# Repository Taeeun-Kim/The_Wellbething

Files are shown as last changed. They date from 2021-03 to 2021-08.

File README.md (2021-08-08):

# The Wellbething

Team project of Information visualization module at TU Dresden University.

A smart device that tells you if you've consumed more than the recommended amount of water per day.

### Used tools and techniques

- Arduino ESP32
- C++
- 3D Printer
- Tinkercad
- Final Cut Pro

### Function

- Temperature
- Humidity
- Water Consumption
- Air Quality

### Documentation

[Link to documentation](https://github.com/Taeeun-Kim/The_Wellbething/blob/main/Documents/Gruppe1_Dokumentation.pdf)

### TechnicalDocumentation

[Link to technical documentation](https://github.com/Taeeun-Kim/The_Wellbething/blob/main/Documents/Gruppe1_Technische_Dokumentation.pdf)

### Overview

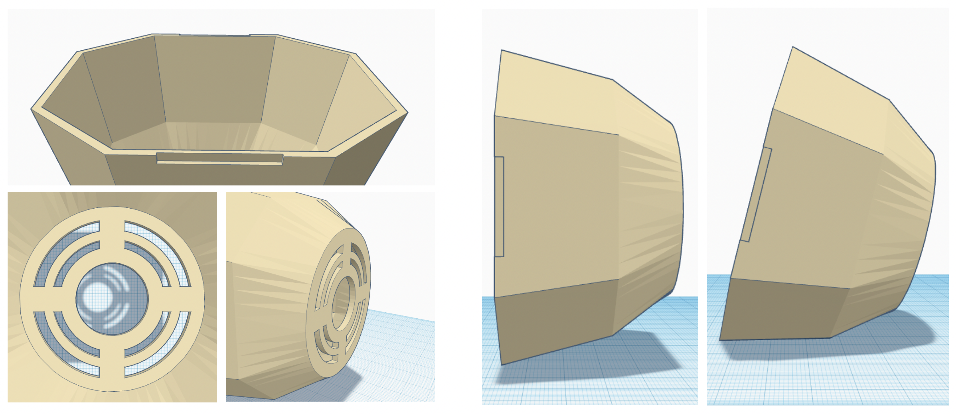
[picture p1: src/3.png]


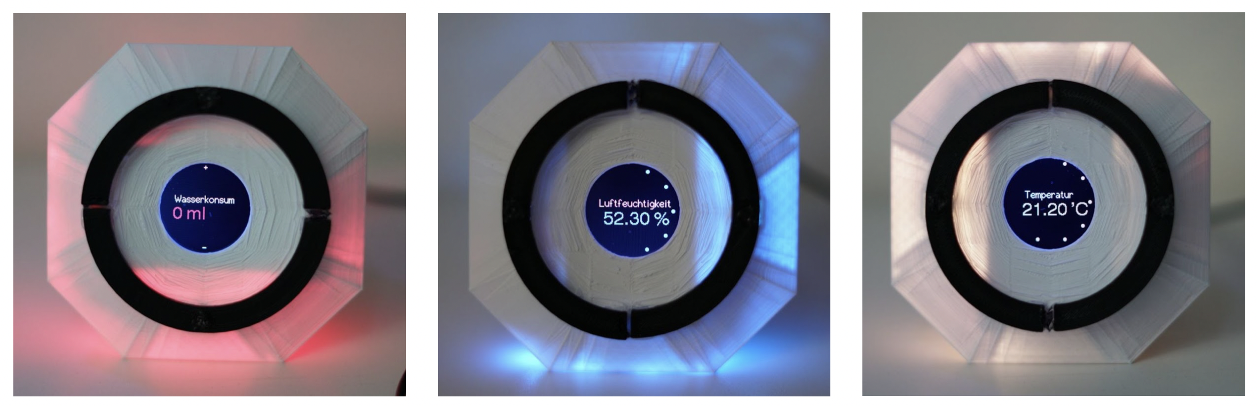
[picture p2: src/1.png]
slack


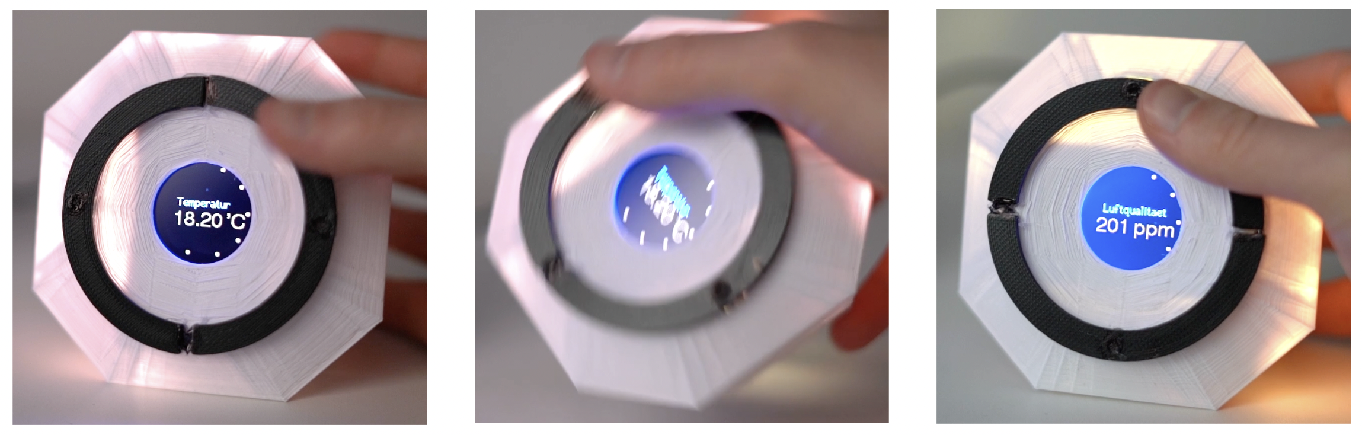
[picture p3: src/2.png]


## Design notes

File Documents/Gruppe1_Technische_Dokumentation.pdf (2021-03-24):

# Technische Dokumentation

### Gruppe 1

### Medieninformatik Projekt Informationsvisualisierung WS 20/21

### Björn Glawe Taeeun Kim Lanea Lilienthal

## Inhaltsverzeichnis

1. Entwicklungsumgebung | 2
1.1 Betriebssystem und Software | 2
1.2 Arduino-Bibliotheken | 2
2. Hardware | 3
2.1 Hardware-Komponenten | 3
2.2 Hardware-Aufbau | 4
3. Software | 5
3.1 Vereinfachtes Klassendiagramm | 5
3.2 Kompilierte Binärdateien und Upload | 6
4. Bedienungsanleitung | 7

## 1. Entwicklungsumgebung

### 1.1 Betriebssystem und Software

- Windows 10
- Visual Studio Code (Version: 1.52.1)
- VSCode Extension: Arduino from Microsoft (Version: 0.3.4)
- Arduino (1.8.13)

### 1.2 Arduino-Bibliotheken

verwendete Arduino-Bibliothek | Version
DHT sensor library | 1.4.0
MQUnifiedsensor | 2.0.1
Adafruit_MPU6050 | 2.0.3
OneWire | 2.3.4
NeoPixelBus | 2.6.0
TFT_eSPI | 2.3.4
SPI | 1.0.0

## 2. Hardware

### 2.1 Hardware-Komponenten

Bauteil | technische Bezeichnung | Funktion
ESP32 | AZDelivery ESP32 Dev Kit C V4 NodeMCU WLAN WiFi Development Board (Link) (https://www.amazon.de/AZDelivery-ESP32-NodeMCU-gratis-eBook/dp/B07Z83MF5W?hvadid=427788576373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) | Mikrocontroller zur Steuerung aller Funktionen
Display | SPI TFT Display 1,8 Zoll mit 128 x 160 Pixeln (mit Kartenslot) (Link) (https://www.amazon.de/AZDelivery-Pixeln-Display-Arduino-Raspberry/dp/B078J5TS2G?hvadid=308872732263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) | visuelle Wiedergabe von Informationen
LED | 8 WS2812B LEDs adressierbare Streifen mit 5050 SMD LEDs | visuelle Wiedergabe von Informationen durch Farbdarstellung
Buttons | Drucktastenschalter | Eingaben durch Drücken des Tasters

DHT-Sensor DHT22 AM2302 Temperatursensor

| und Luftfeuchtigkeitssensor mit Platine (Link) (https://www.az-delivery.de/products/dht22-temperatursensor-modul) | Messung von Temperatur und Luftfeuchtigkeit
MQ-Sensor | MQ-135 Gas Sensor Luftqualität Modul (Link) (https://www.amazon.de/AZDelivery-MQ-135-Sensor-Luftqualit%C3%A4t-Arduino/dp/B07CNNKQ5R?hvadid=380161958296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) | Messung von Luftqualität, misst Anteil an Luftpartikeln
Gyroskop | GY-521 MPU-6050 3-Achsen-Gyroskop und Beschleunigungssensor (Link) (https://www.az-delivery.de/products/gy-521-6-achsen-gyroskop-und-beschleunigungssensor) | Messung von Bewegung, hier Rotation

### 2.2 Hardware-Aufbau

Folgende Grafik zeigt die Verbindungen auf der Platine zu den einzelnen Bauteilen. Dabei dient die Platine als ein kompaktes Mittelstück, an dem alle Bauteile miteinander vereint werden. Das Display wird auf der Rückseite direkt verbunden, alle anderen Sensoren sind auf der Vorderseite direkt oder über Kabel verbunden. Alle notwendigen Verbindungen gehen von der Plantine aus zum ESP32. Durch die Platine werden vor allem 5V, 3v3 und GND nur jeweils einmal mit dem ESP32 verbunden. Dies ermöglicht eine relativ kompakte Bauweise im Tangible.

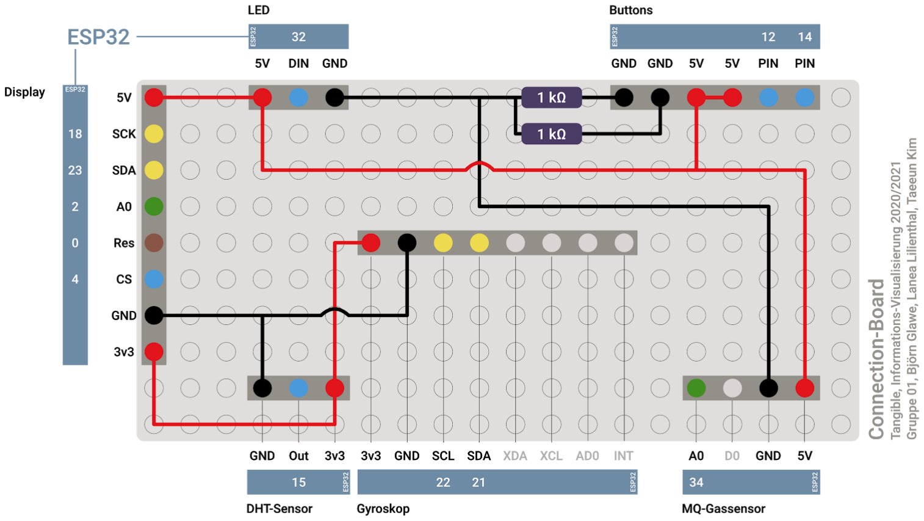
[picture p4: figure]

In der folgenden Abbildung finden sich die Verbindungen von der jeweiligen Komponente zum direkten Pin-Anschlüsse am ESP32. Auf der linken Seite befinden sich jeweils die ESP32-Pins und auf der rechten Seite die Komponenten-Pins. Graue Kreise (Pins) werden nicht angeschlossen.

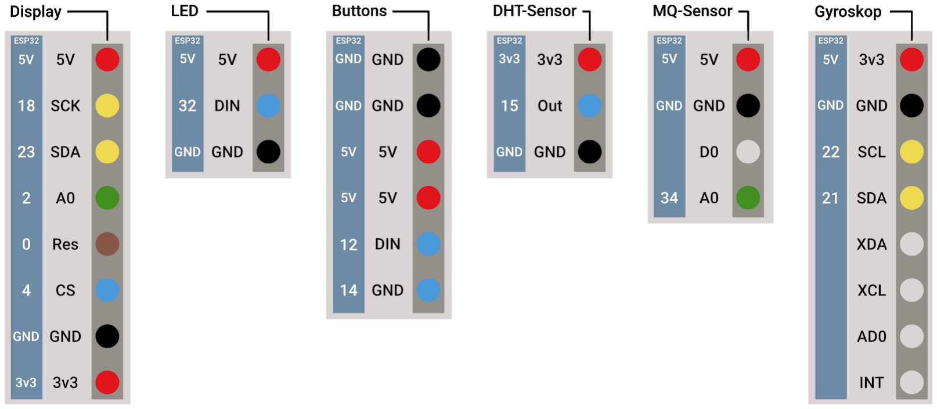
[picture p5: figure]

## 3. Software

### 3.1 Vereinfachtes Klassendiagramm

Zentral ist die main.ino-Datei. Alle Funktionen werden hier initialisiert, aufgerufen und verknüpft. Zu jedem Modul, bzw. für den Wasserkonsum zusätzlich, existiert eine eigene Klasse, in der für das Projekt notwendige Funktionen implementiert wurden. Diese können jeweils von der main.ino aufgerufen und verwendet werden.

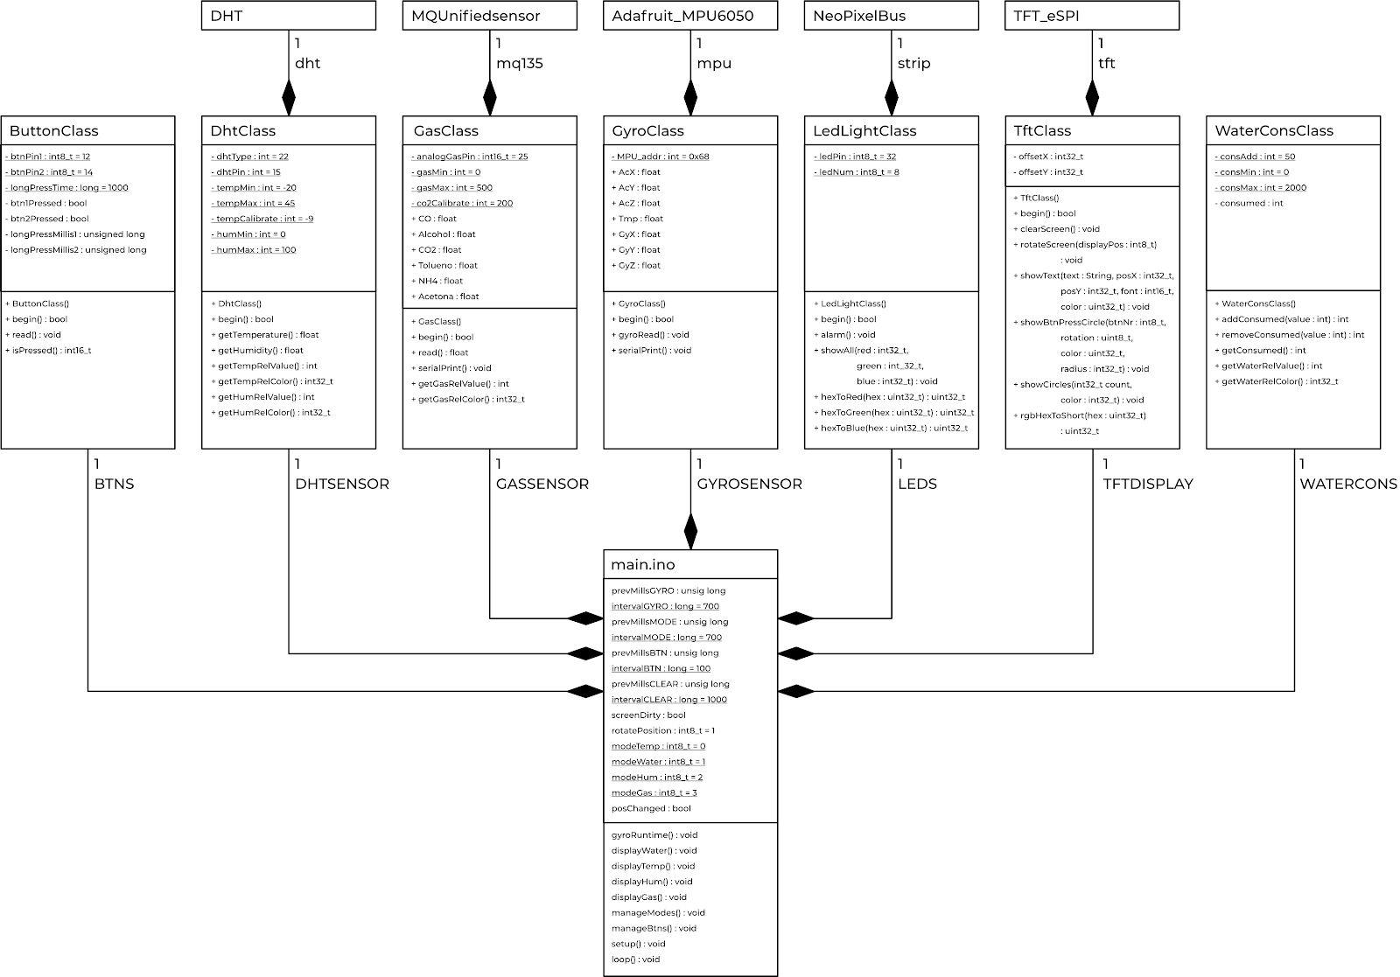
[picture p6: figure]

### 3.2 Kompilierte Binärdateien und Upload

Unter ./build sind alle kompilierten Dateien und Sourcecode nach dem letzten build-Vorgang zu finden, inklusive Bibliotheken.
In der Konfigurationsdatei .vscode/arduino.json werden durch die Angabe von “output”: “build” alle Dateien die im Projekt zur Kompilierung, sowie auch die kompilierten Binärdateien, im Ordner ./build abgelegt.
Für den Upload auf den ESP32 werden folgende Dateien benötigt:
- build\button.cpp.bin
- build\button.cpp.partitions.bin
Die Bezeichnung button innerhalb des Dateinamen spielt dabei keine Rolle.

Für den Upload der Binärdateien lautet der Konsolenbefehl wie folgt:

Um den Konsolenbefehl auf dem eigenen System zu finden, geht man wie folgt vor. In der Arduino IDE unter File>Preferences die Option “Show verbose output during” > “upload” den Haken setzen (true).
Daraufhin einen Upload mit Arduino IDE auf einen ESP32 starten und in der letzten Zeile vom Arduino Output, bevor der Upload startet, ist der Uploadbefehl mit allen Pfadangaben in der eigenen eingerichteten Entwicklungsumgebung zu finden. Diesen Befehl kopieren und entsprechende Pfade (in dem Beispiel grün markiert) durch die kompilierten Binärdatei-Pfade ersetzen.

farbliche Codierung:
ESP-Uploader-Files (kommen mit der ESP32-Board-Packages) Controller-Configurations (spezifische Einstellungen für den Upload)
kompilierte Projektdateien (zuvor beschriebene Dateien unter ./build)

schematischer Upload-Konsolen-Befehl ([...] kennzeichnet den Systempfad zur Datei):

[...]/esptool.exe --chip esp32 --port COM3 --baud 921600 --before default_reset --after hard_reset write_flash -z --flash_mode dio --flash_freq 80m --flash_size detect 0xe000 [...]/boot_app0.bin 0x1000 [...]/bootloader_qio_80m.bin 0x10000 [...]\button.cpp.bin 0x8000 [...]\button.cpp.partitions.bin

Beispiel von der eigenen Entwicklungsumgebung:

C:\Users\rumpe\AppData\Local\Arduino15\packages\esp32\tools\esptool_py\2.6.1/esptool.exe --chip esp32 --port COM3 --baud 921600 --before default_reset --after hard_reset write_flash -z --flash_mode dio --flash_freq 80m --flash_size detect 0xe000 C:\Users\rumpe\AppData\Local\Arduino15\packages\esp32\hardware\esp32\1.0.4/tools/partition s/boot_app0.bin 0x1000
C:\Users\rumpe\AppData\Local\Arduino15\packages\esp32\hardware\esp32\1.0.4/tools/sdk/bin/b ootloader_qio_80m.bin 0x10000 C:\Users\rumpe\CloudStation\Drive\UNI_5\InfoVis\infovis-2021-gruppe-1\build\button.cpp.bin 0x8000
C:\Users\rumpe\CloudStation\Drive\UNI_5\InfoVis\infovis-2021-gruppe-1\build\button.cpp.par titions.bin

## 4. Bedienungsanleitung

Das Tangible hat vier grundlegende Funktionen, die für den Nutzer relevant sind:
- zwischen den verschiedenen Ausgabewerten wechseln
- den aktuellen Wert nachschauen
- Getrunkenes eintragen
- Warnfunktion zum Trinken.

Es gibt vier unterschiedliche Ansichten (Wasserkonsum, Temperatur, Luftfeuchtigkeit und Luftqualität) zwischen denen der Nutzer wechseln kann. Das Wechseln funktioniert, indem das Tangible um 90° gedreht wird. Das Tangible ist hierbei so designt, dass es auf allen dieser vier Seiten stehen kann.
Sobald das Tangible gedreht wird, wechselt die Ansicht. Wenn das Tangible also z.B. auf Temperatur eingestellt ist und es gedreht wird, wechselt es zur nächsten Ansicht (z.B. Luftfeuchtigkeit).
Jede dieser Ansichten zeigt den jeweiligen aktuellen Wert im Raum in dem das Tangible sich befindet. Also die aktuelle Temperatur in °C, Luftfeuchtigkeit in %, Luftqualität in ppm und die Menge des bisher Getrunkenen des Tages in ml. Zusätzlich zur textuellen Anzeige des Wertes befindet sich am Rand des Displays eine visuelle Anzeige in Form von Kreisen, deren Anzahl und Farbe je nach Wert variiert. Ein höherer Temperaturwert bedeutet also auch mehr Punkte.
Die Farbe der Punkte orientiert sich auch am aktuellen Wert und bezieht sich auf die Farbskala der jeweiligen Ansicht (z.B. Dunkelrot für sehr hohe Temperaturen). Zusätzlich dazu leuchtet das Tangible in der entsprechenden Farbe.
Bei der Wasserkonsum-Ansicht gibt es des Weiteren die Funktion des Eintragens. Dazu befinden sich zwei Knöpfe ober- und unterhalb des Displays. Der obere Knopf ist hierbei dazu da die Milliliterzahl des Getrunkenen anzupassen. Sobald der Knopf gedrückt wird, erhöht sich die Anzahl in 50 ml Schritten und das Display und die Farbe des Tangibles passen sich entsprechend an. Mit der unteren Taste kann die Zahl jeweils um 50 ml verringert werden (z.B. bei Fehleingaben).
Letztlich gibt es noch eine Warnfunktion, die aber bisher noch nicht umgesetzt ist. Diese soll den Nutzer in bestimmten Zeitabschnitten warnen, wenn über einen längeren Zeitraum nichts oder nicht genug getrunken wurde. Diese Warnung erfolgt über ein Aufleuchten und eine Vibration des Tangibles, die ein paar Sekunden anhält.

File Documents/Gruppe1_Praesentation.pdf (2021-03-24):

# Konzeption und Design eines Tangibles zur Unterstützung des gesunden Wasserbedarfs

Professur Mediengestaltung

Fakultät Informatik / TU Dresden

KP Medieninformatik – Informationsvisualisierung

Björn Glawe
Taeeun Kim
Lanea Lilienthal

## Fr, 12. MRZ (virtuell)

# The Wellbething

# Gliederung

# ende

# Idee

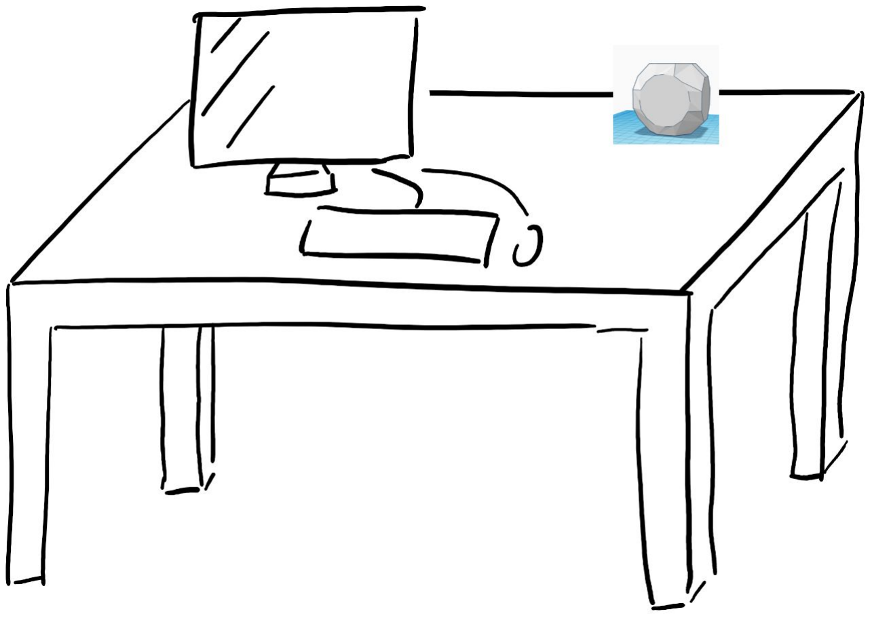
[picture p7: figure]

# - häufig zu geringe Flüssigkeitsaufnahme - Flüssigkeitsbedarf variiert durch Umgebung - Wohlbefinden und Leistungsfähigkeit erhöhen - stets präsentes Tangible mit Erinnerungen - jederzeit erreichbar als mobile App

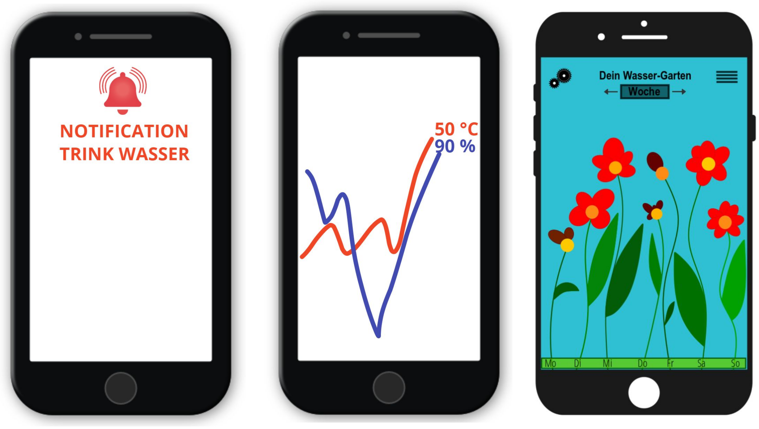
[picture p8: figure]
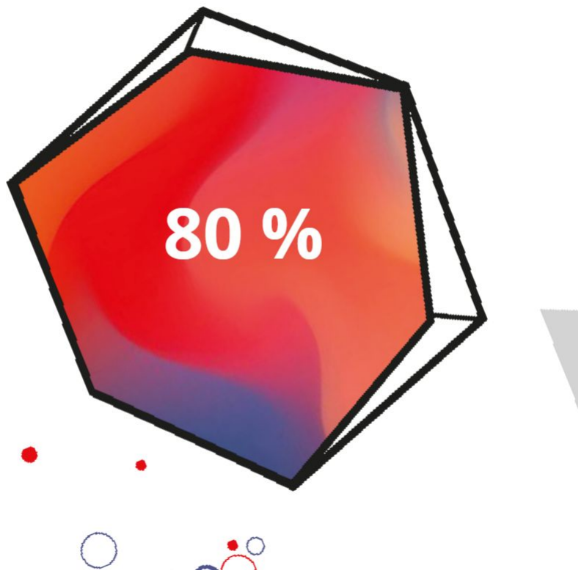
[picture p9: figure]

KP Medieninformatik - Informationsvisualisierung | WS 20/21 | Björn Glawe, Taeeun Kim, Lanea Lilienthal | 3

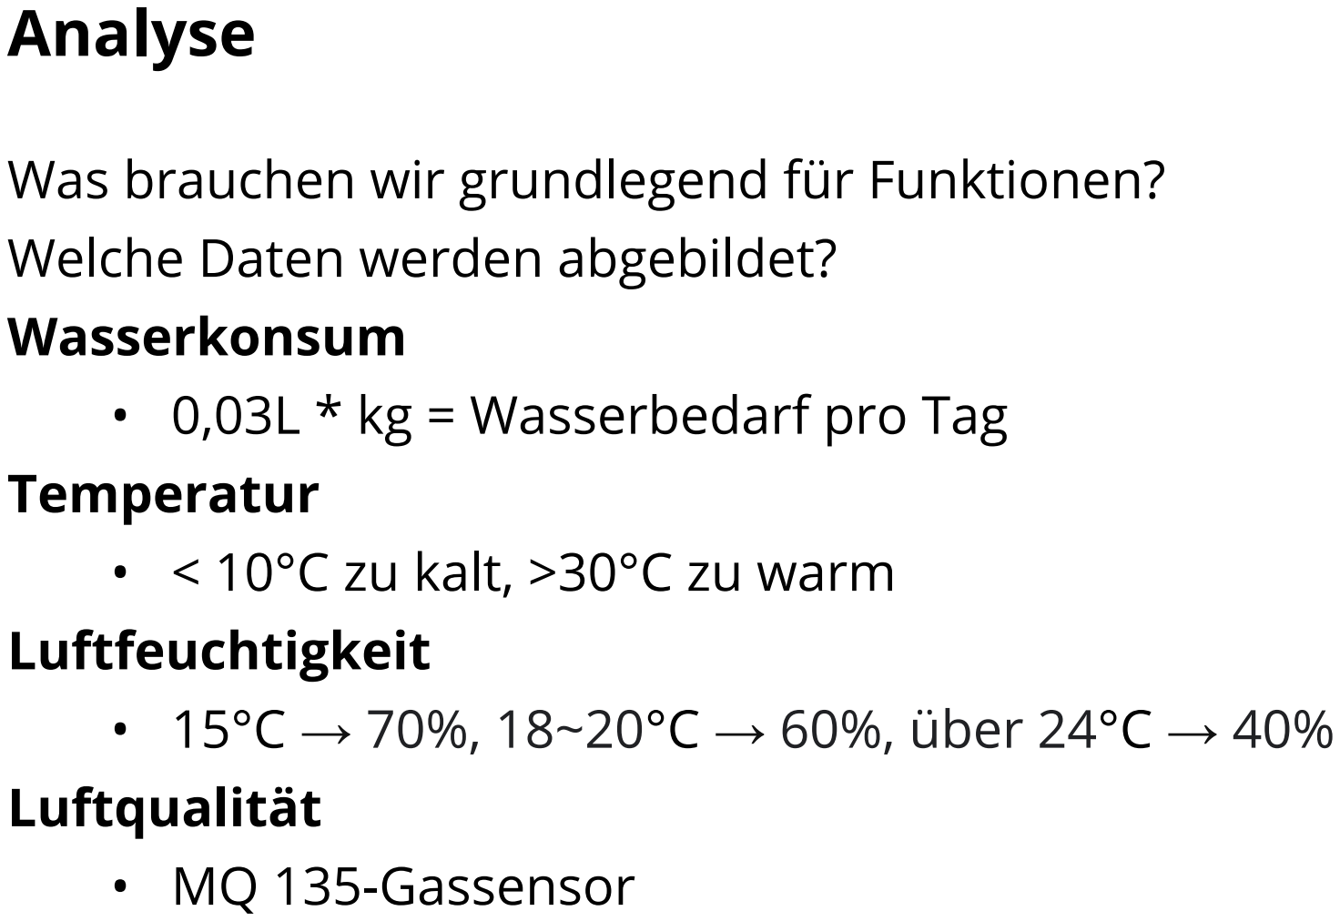
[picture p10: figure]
Analyse; Welche Daten werden abgebildet?; Wasserkonsum • 0,03L * kg = Wasserbedarf pro Tag; Temperatur • < 10°C zu kalt, >30°C zu warm Luftfeuchtigkeit; Luftqualität; • MQ 135-Gassensor

# Was brauchen wir grundlegend für Funktionen?

# - 15°C → 70%, 18~20°C → 60%, über 24°C → 40%

KP Medieninformatik - Informationsvisualisierung | WS 20/21 | Björn Glawe, Taeeun Kim, Lanea Lilienthal | 4

# Design Körper - 3D CAD Modelle

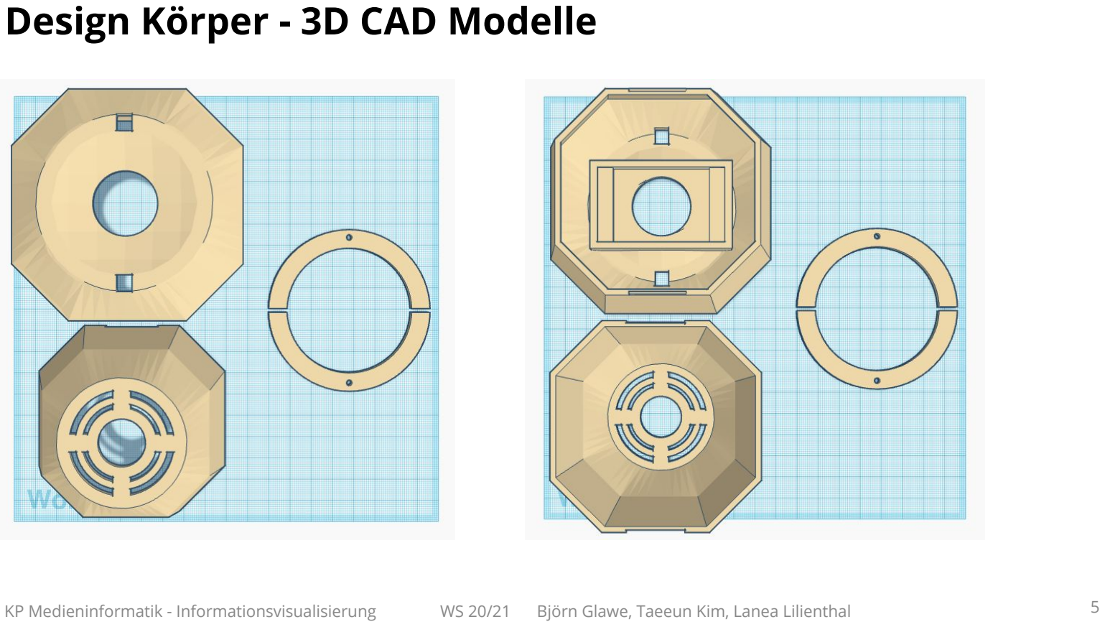
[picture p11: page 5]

KP Medieninformatik - Informationsvisualisierung | WS 20/21 | Björn Glawe, Taeeun Kim, Lanea Lilienthal | 5

# Design Körper - Vorderseite

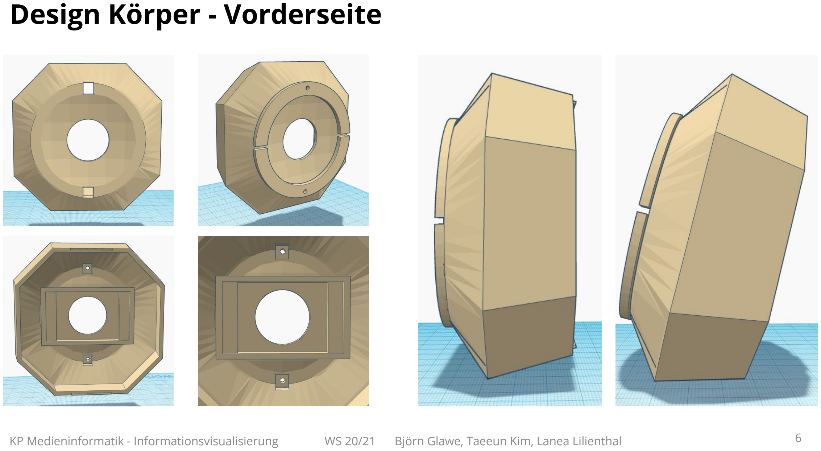
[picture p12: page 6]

KP Medieninformatik - Informationsvisualisierung | WS 20/21 | Björn Glawe, Taeeun Kim, Lanea Lilienthal | 6

# Design Körper - Rückseite

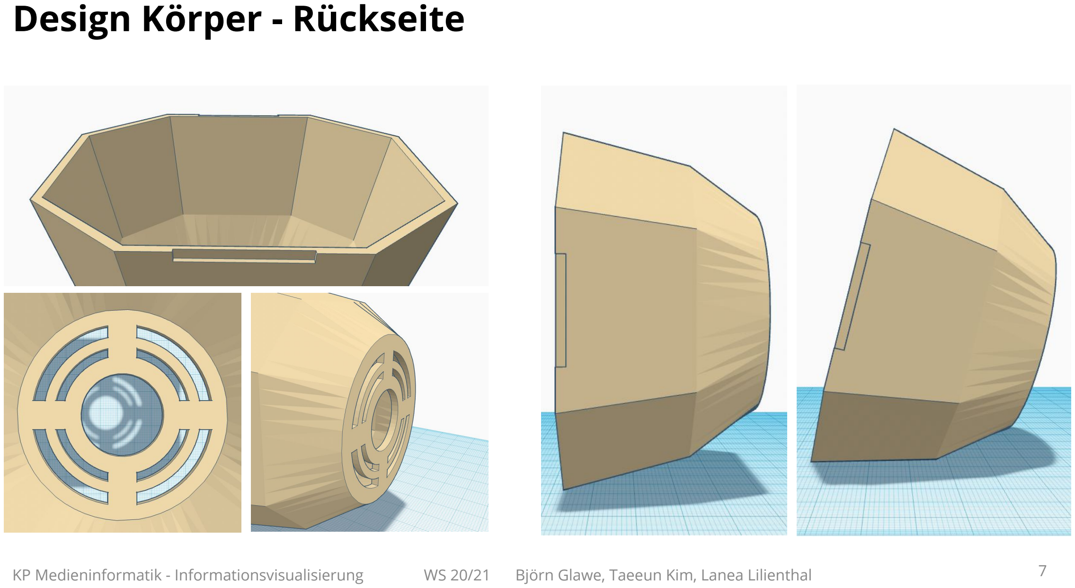
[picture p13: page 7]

KP Medieninformatik - Informationsvisualisierung | WS 20/21 | Björn Glawe, Taeeun Kim, Lanea Lilienthal | 7

# Design Körper - High Fidelity Prototyp

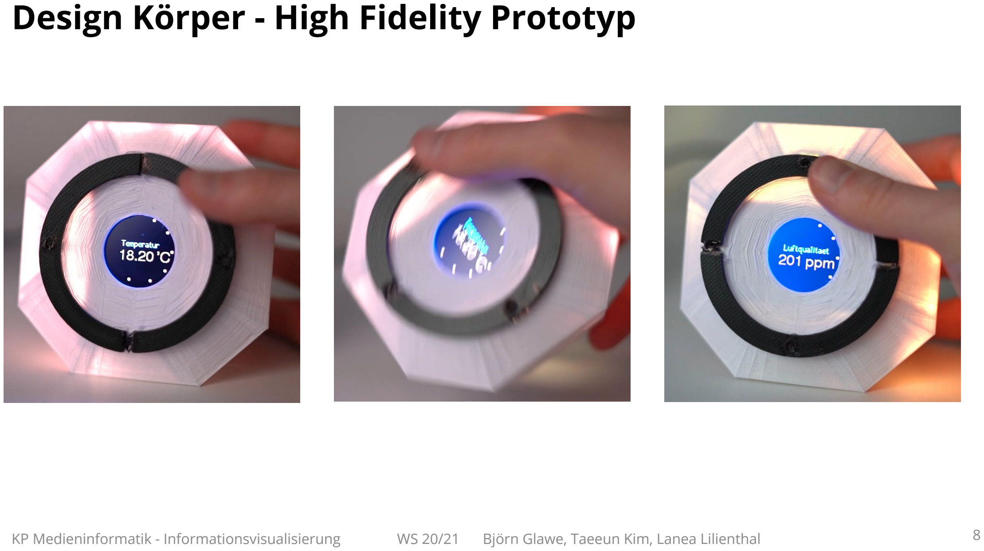
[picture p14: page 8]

KP Medieninformatik - Informationsvisualisierung | WS 20/21 | Björn Glawe, Taeeun Kim, Lanea Lilienthal | 8

# Screendesign - Tangible

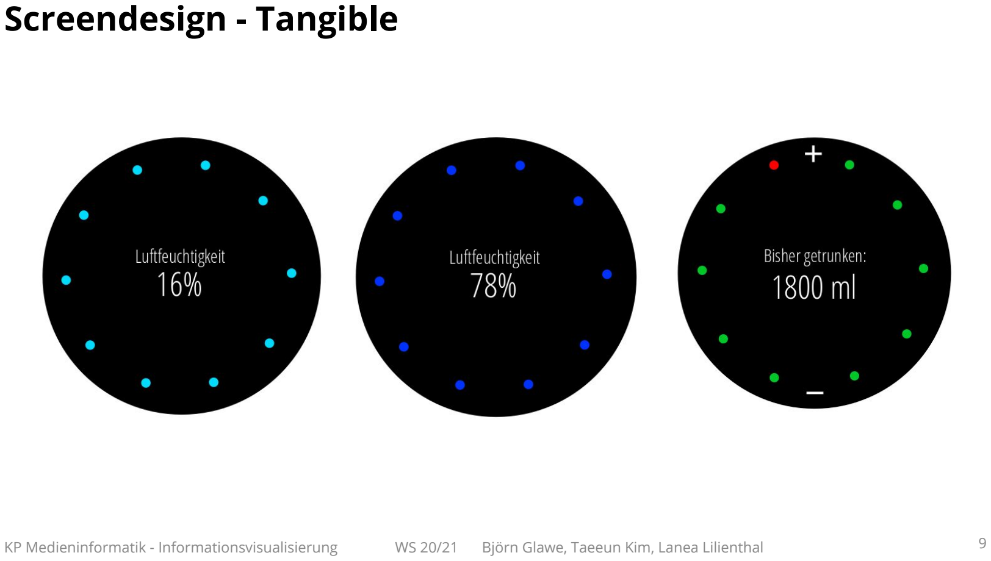
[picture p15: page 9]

KP Medieninformatik - Informationsvisualisierung | WS 20/21 | Björn Glawe, Taeeun Kim, Lanea Lilienthal | 9

# Screendesign - Tangible

# Alternative Designs

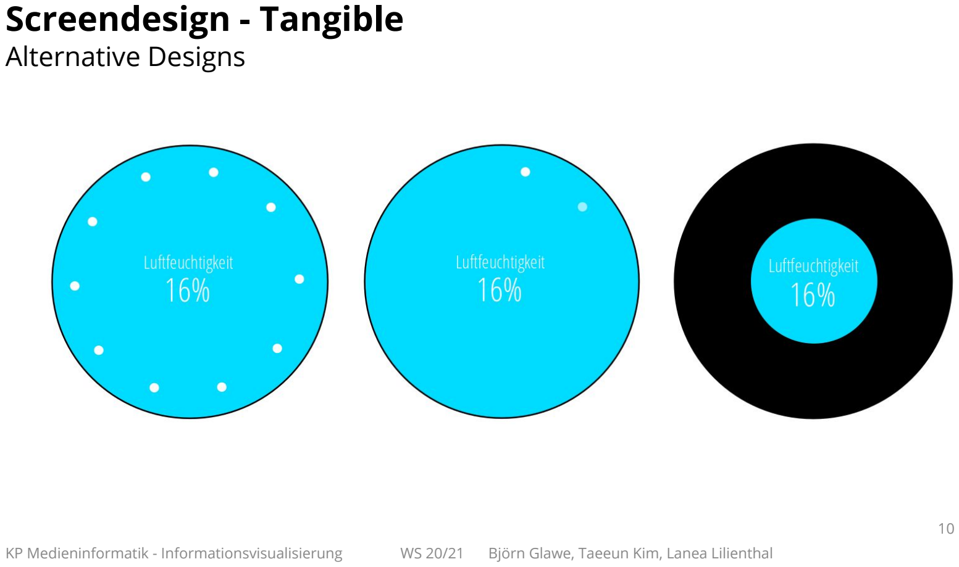
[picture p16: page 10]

KP Medieninformatik - Informationsvisualisierung | WS 20/21 | Björn Glawe, Taeeun Kim, Lanea Lilienthal

# Screendesign - Tangible

# Finale Umsetzung

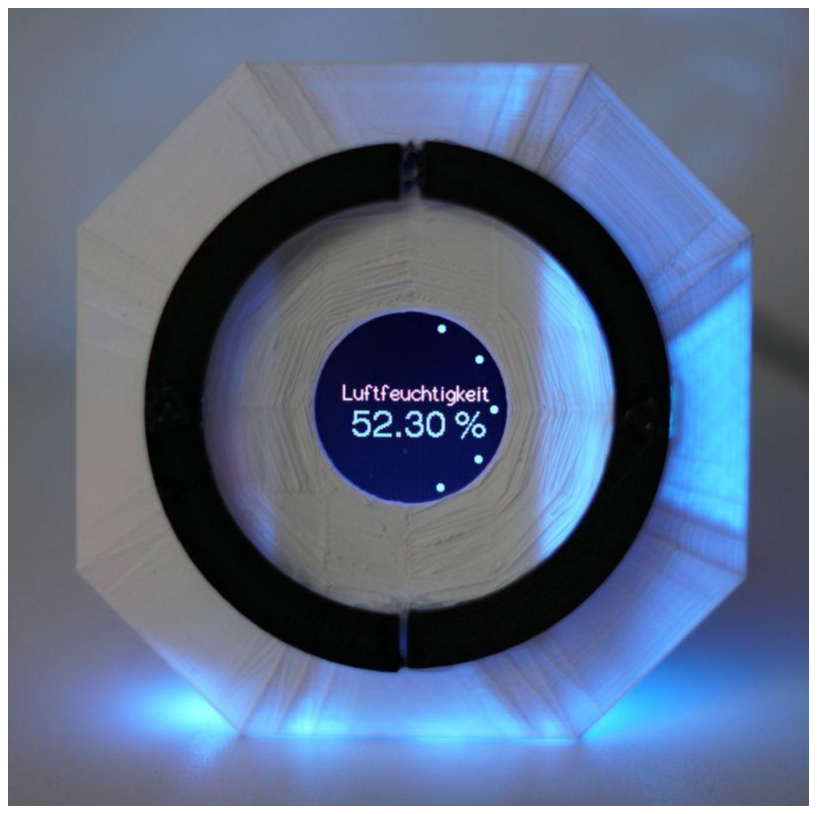
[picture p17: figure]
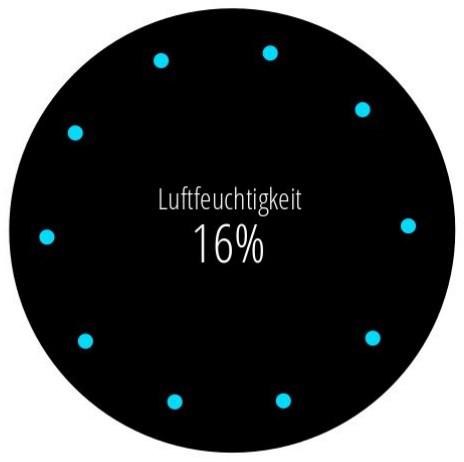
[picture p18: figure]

# Screendesign - Tangible

# Finale Umsetzung

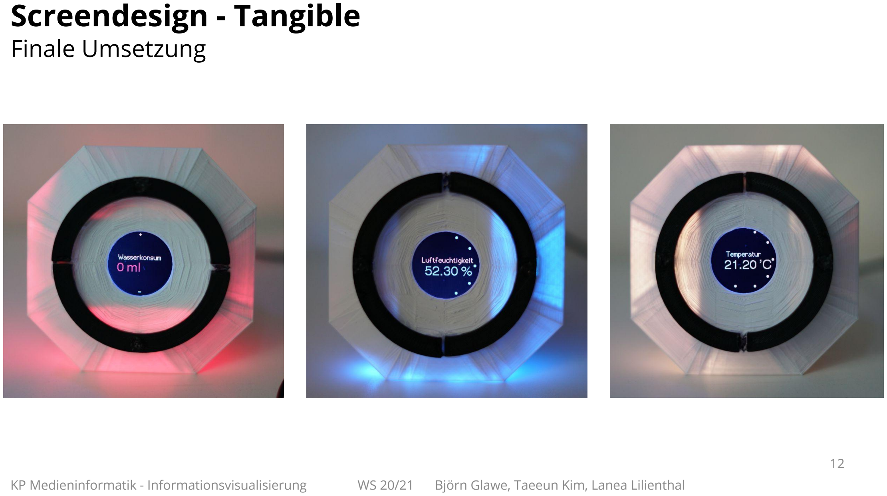
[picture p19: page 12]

# Funktionen - Tangible

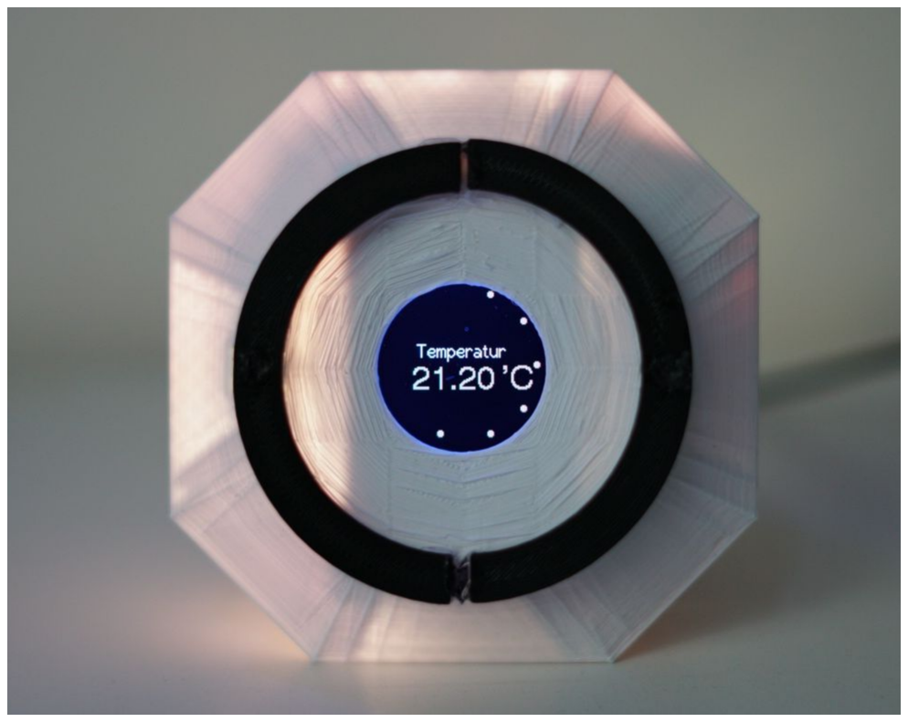
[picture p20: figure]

# Anzeige - aktuelle Zahlenwerte & farbliches Leuchten

# Drehen - Ansichtswechsel

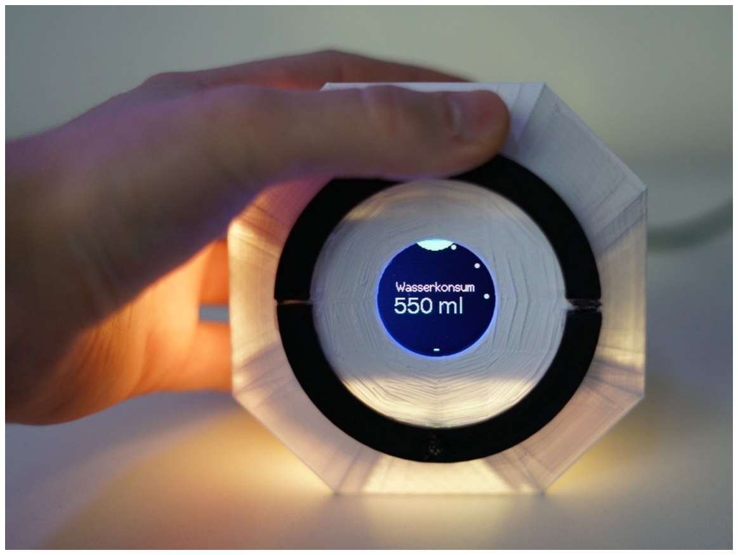
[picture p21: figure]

# Eingabe - Wasserkonsum hinzufügen / entfernen

# Erinnerung

# - Blinken & Vibrieren bei geringe Flüssigkeit oder schlechte Luftqualität

KP Medieninformatik - Informationsvisualisierung | WS 20/21 | Björn Glawe, Taeeun Kim, Lanea Lilienthal | 13

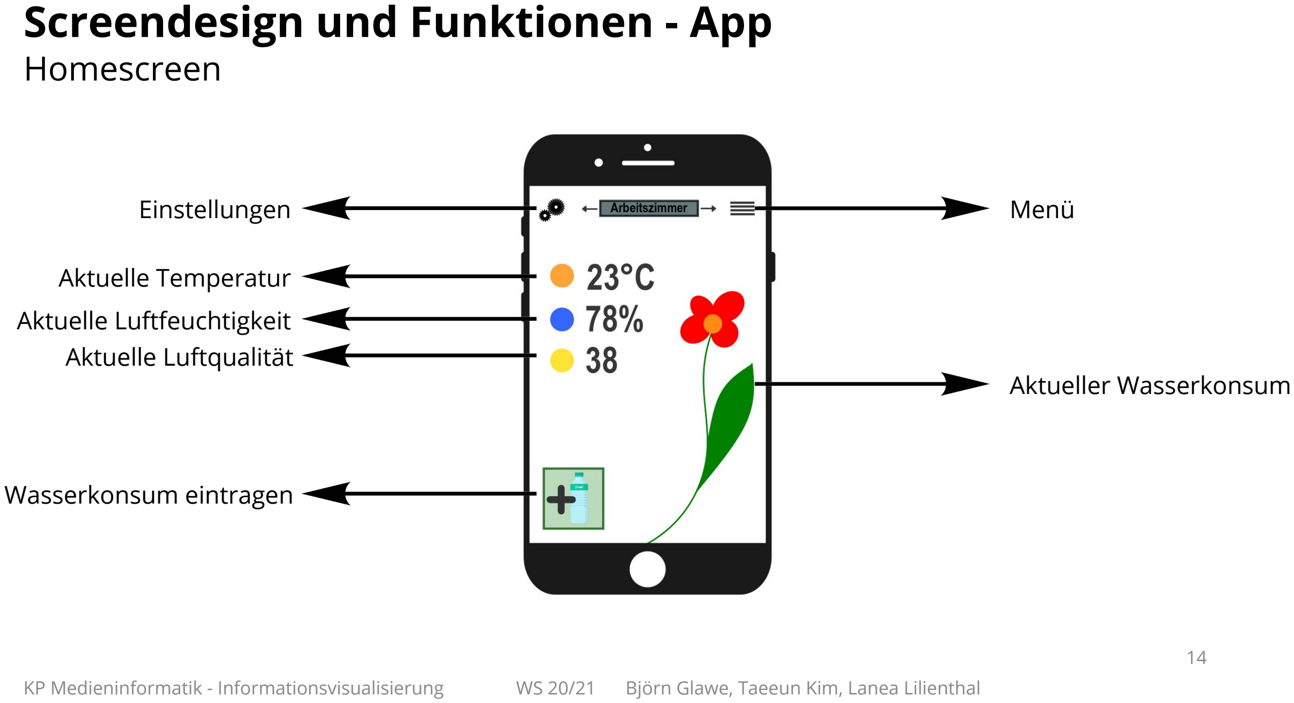
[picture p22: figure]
Screendesign und Funktionen - App; Einstellungen; Aktuelle Temperatur; Aktuelle Luftfeuchtigkeit; Aktueller Wasserkonsum; Menü; Aktuelle Luftqualität; Wasserkonsum eintragen; Homescreen

# Screendesign und Funktionen - App

# Verläufe

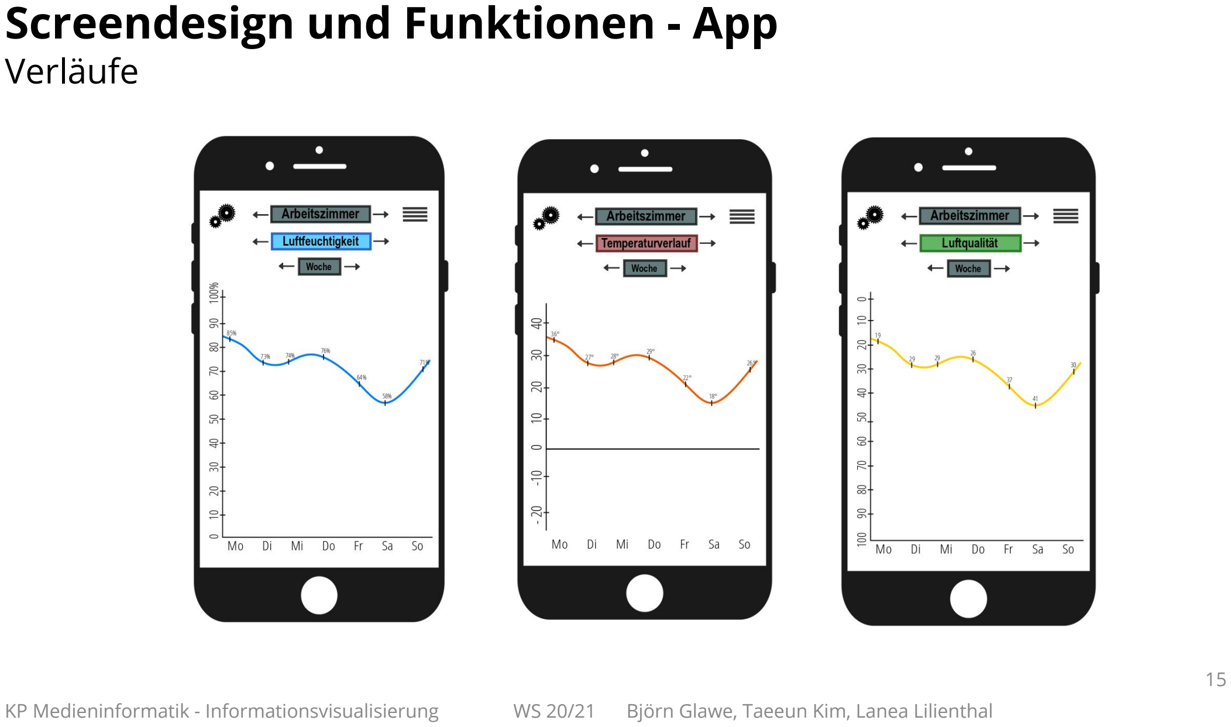
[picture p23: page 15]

# Screendesign und Funktionen - App

# Juxtaposed View

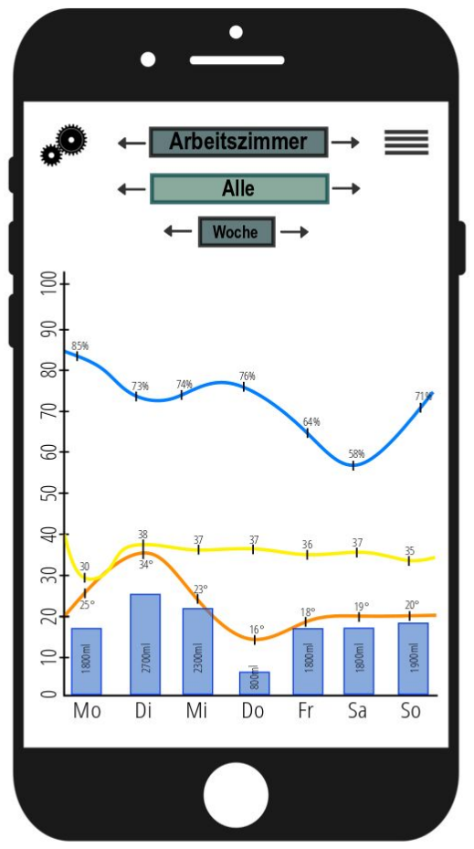
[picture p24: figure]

# Screendesign und Funktionen - App

# Wassergarten - Wochenansicht

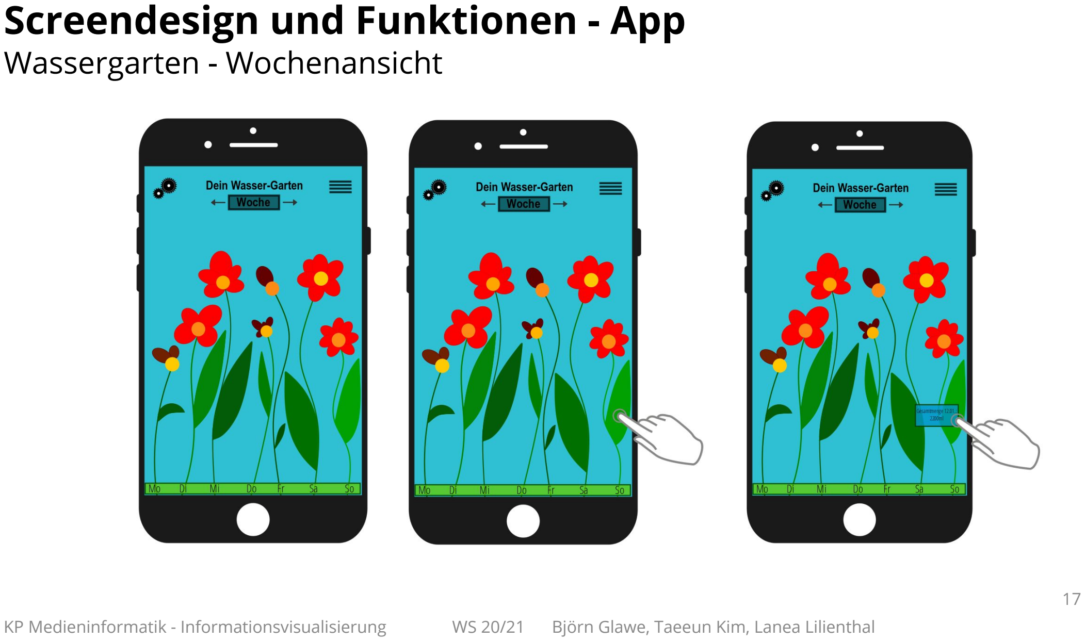
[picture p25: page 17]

# Screendesign und Funktionen - App

# Wassergarten - Tagesansicht

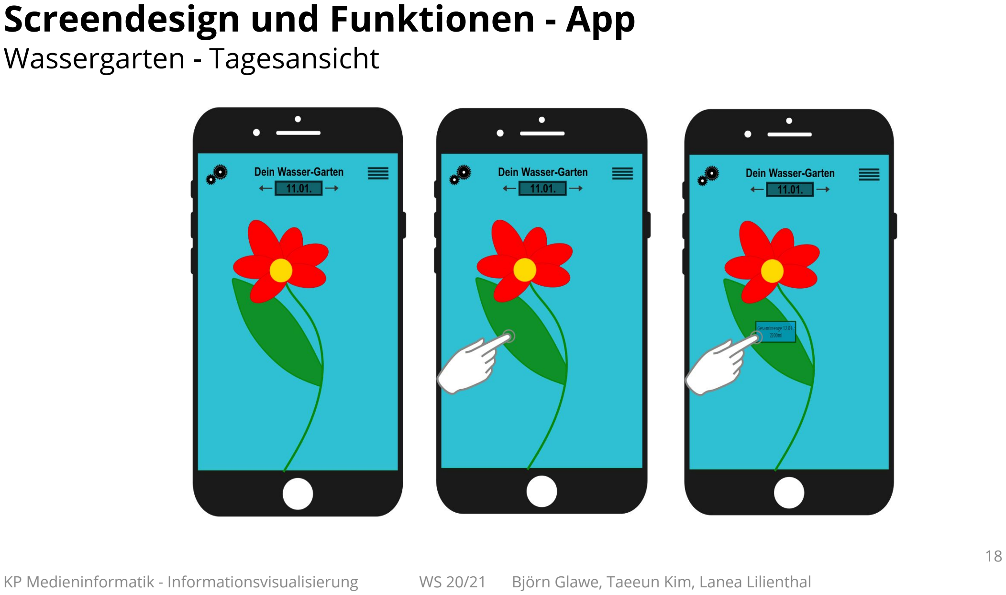
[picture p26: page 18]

# Screendesign und Funktionen - App

# Wasserkonsum eintragen

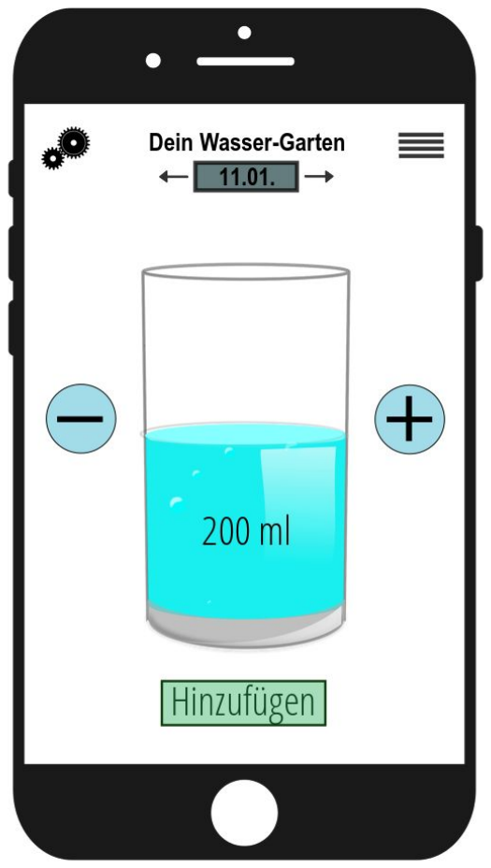
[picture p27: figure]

# Quellen

1. Gesundheitsportal Österreich -; 3. The Engineering ToolBox -

# https://www.gesundheit.gv.at/leben/ernaehrung/info/fluessigkeitsbedarf 2. Chemie.de - https://www.chemie.de/lexikon/Luftfeuchtigkeit.html

# https://www.engineeringtoolbox.com/air-contaminants-limits-d_1538.html 4. Deutsche Gesellschaft für Ernährung - https://www.dge.de/ 5. Instructables - https://www.instructables.com/Air-Qualiy-Monitoring/

KP Medieninformatik - Informationsvisualisierung | WS 20/21 | Lanea Lilienthal | 20

# Vielen Dank!


KP Medieninformatik - Informationsvisualisierung | WS 20/21 | Lanea Lilienthal | 21

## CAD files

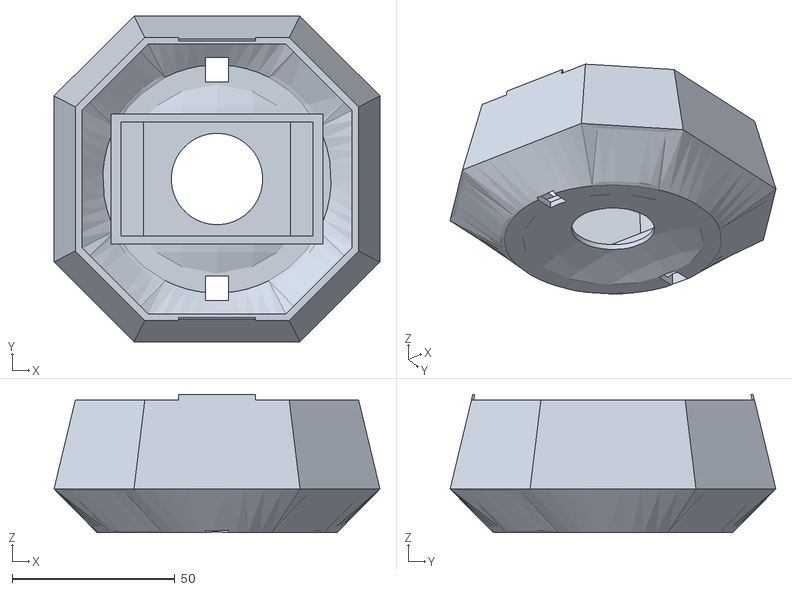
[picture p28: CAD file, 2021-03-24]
Körperkonstruktion/final-version/Tangible-front.stl
100.1 x 100.0 x 42.5

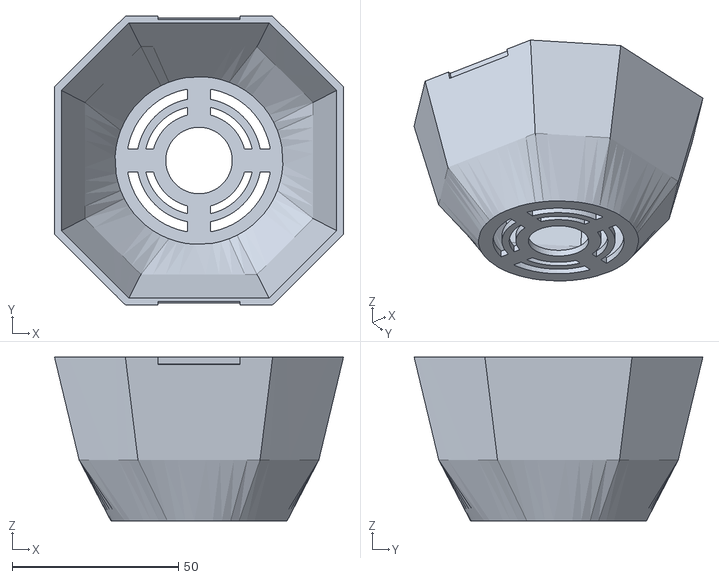
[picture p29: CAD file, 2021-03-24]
Körperkonstruktion/final-version/Tangible-back.stl
87.0 x 86.9 x 49.2

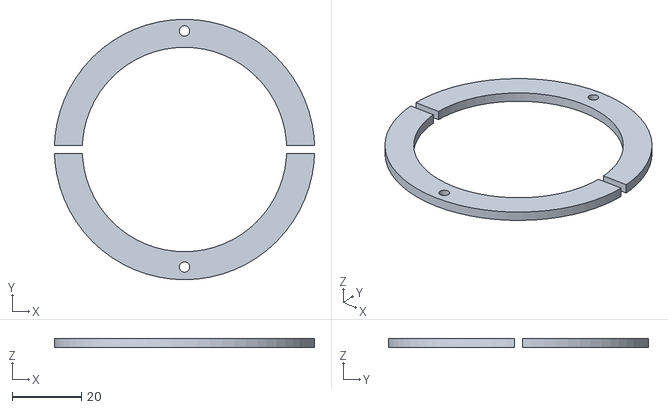
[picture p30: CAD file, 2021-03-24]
Körperkonstruktion/final-version/Button-Halbkreise.stl
74.9 x 75.0 x 2.69

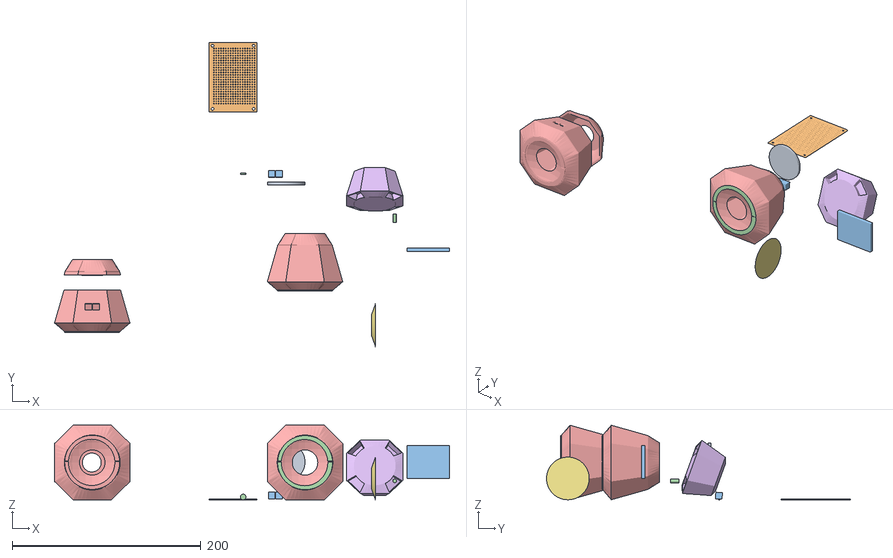
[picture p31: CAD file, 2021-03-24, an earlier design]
Körperkonstruktion/old-version/OBJ/Praktischer Körper mit den Buttonlöchern/tinker.obj
418.3 x 322.0 x 79.0

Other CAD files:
Körperkonstruktion/old-version/STL/Praktischer Körper mit den Buttonlöchern.stl
Körperkonstruktion/final-version/Button-Halbkreise.obj
Körperkonstruktion/final-version/Tangible-back.obj
Körperkonstruktion/final-version/Tangible-front.obj

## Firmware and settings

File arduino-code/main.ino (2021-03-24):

#include <Arduino.h>
#include "tftDisplay.h"
#include "dhtSensor.h"
#include "gyroSensor.h"
#include "gasSensor.h"
#include "button.h"
#include "ledLight.h"
#include "waterCons.h"

// ---------------- VARIABLES ---------------- //
// timing / delay
unsigned long prevMillsGYRO = 0;
const long intervalGYRO = 700;
unsigned long prevMillsMODE = 0;
const long intervalMODE = 700;
unsigned long prevMillsBTN = 0;
const long intervalBTN = 100;

unsigned long prevMillsCLEAR = 0;
const long intervalCLEAR = 1000;
bool screenDirty = true;

/* 0 - drinking 1 - temperature 2 - humidity 3 - gas */
int8_t rotatePosition = 1;
const int8_t modeTemp = 0;
const int8_t modeWater = 1;
const int8_t modeHum = 2;
const int8_t modeGas = 3;
bool posChanged = true;

// ------------------- runtime CHECKS -------------------
/**
 * checks rotation changes
 * triggers and sets new position after change
 */
void gyroRuntime()
{
  GYROSENSOR.gyroRead();
  
  if (GYROSENSOR.GyX > 1.4)
  {
    rotatePosition = ((rotatePosition + 3) % 4);
    posChanged = true;
  }
  else if (GYROSENSOR.GyX < -1.4)
  {
    rotatePosition = ((rotatePosition + 1) % 4);
    posChanged = true;
  }
}

/**
 * interface of consumed water
 */
void displayWater()
{
  uint32_t color = WATERCONS.getWaterRelColor();
  uint32_t colorS = TFTDISPLAY.rgbHexToShort(color);

  LEDS.showAll(LEDS.hexToRed(color), LEDS.hexToGreen(color), LEDS.hexToBlue(color));
  TFTDISPLAY.showText("Wasserkonsum", 23, 45);
  TFTDISPLAY.showText("+", 63, 0);
  TFTDISPLAY.showText("-", 63, 113);
  TFTDISPLAY.showText(String(WATERCONS.getConsumed()) + " ml", 20, 63, 4, colorS);
  TFTDISPLAY.showCircles(WATERCONS.getWaterRelValue(), colorS);
}

/**
 * interface of temperature
 */
void displayTemp()
{
  uint32_t color = DHTSENSOR.getTempRelColor();
  uint32_t colorS = TFTDISPLAY.rgbHexToShort(color);

  LEDS.showAll(LEDS.hexToRed(color), LEDS.hexToGreen(color), LEDS.hexToBlue(color));
  TFTDISPLAY.showText("Temperatur", 29, 45);
  float temp = DHTSENSOR.getTemperature();
  TFTDISPLAY.showText(String(temp) + " 'C", 25, 63, 4, colorS);
  //TFTDISPLAY.showText(String(GYROSENSOR.Tmp) + " 'C", 40, 85);
  TFTDISPLAY.showCircles(DHTSENSOR.getTempRelValue(), colorS);
}

/**
 * interface of humidity
 */
void displayHum()
{
  uint32_t color = DHTSENSOR.getHumRelColor();
  uint32_t colorS = TFTDISPLAY.rgbHexToShort(color);

  LEDS.showAll(LEDS.hexToRed(color), LEDS.hexToGreen(color), LEDS.hexToBlue(color));
  TFTDISPLAY.showText("Luftfeuchtigkeit", 20, 45);
  float hum = DHTSENSOR.getHumidity();
  TFTDISPLAY.showText(String(hum) + " %", 25, 63, 4, colorS);
  TFTDISPLAY.showCircles(DHTSENSOR.getHumRelValue(), colorS);
}

/**
 * interface of gas (CO2)
 */
void displayGas()
{
  uint32_t color = GASSENSOR.getGasRelColor();
  uint32_t colorS = TFTDISPLAY.rgbHexToShort(color);

  LEDS.showAll(LEDS.hexToRed(color), LEDS.hexToGreen(color), LEDS.hexToBlue(color));
  TFTDISPLAY.showText("Luftqualitaet", 25, 45);
  TFTDISPLAY.showText(String(int(round(GASSENSOR.read()))) + " ppm", 17, 63, 4, colorS);
  TFTDISPLAY.showCircles(GASSENSOR.getGasRelValue(), colorS);
}

/**
 * checks which interface to display
 */
void manageModes()
{
  if (posChanged)
  {
    TFTDISPLAY.rotateScreen(rotatePosition);
    TFTDISPLAY.clearScreen();
    posChanged = false;
  }

  switch (rotatePosition)
  {
  case modeTemp:
    displayTemp();
    break;
  case modeWater:
    displayWater();
    break;
  case modeHum:
    displayHum();
    break;
  case modeGas:
    displayGas();
    break;
  default:
    LEDS.showAll(0, 100, 100);
  }
}

/**
 * checks button input and manages action
 */
void manageBtns()
{
  int16_t btnReturn = BTNS.isPressed();

  // small delay before refresh screen to leave a button response on screen
  if (btnReturn != 0) { // no button input
    prevMillsCLEAR = millis();
    screenDirty = true;
  }

  // no button interaction in different modes
  if (rotatePosition != modeWater) return;

  // buttons visualization
  switch (btnReturn)
  {
  case 0: // clear screen
    if (millis() - prevMillsCLEAR >= intervalCLEAR && screenDirty)
    {
      TFTDISPLAY.clearScreen();
      prevMillsMODE = 0;
      screenDirty = false;
    }
    break;
  case 1:
    TFTDISPLAY.showBtnPressCircle(1, rotatePosition, TFT_GREEN, 20);
    break;
  case 2:
    TFTDISPLAY.showBtnPressCircle(2, rotatePosition, TFT_RED, 20);
    break;
  case 3:
    TFTDISPLAY.showBtnPressCircle(1, rotatePosition, TFT_GREEN);
    break;
  case 4:
    TFTDISPLAY.showBtnPressCircle(2, rotatePosition, TFT_RED);
    break;
  case 5:
    TFTDISPLAY.showBtnPressCircle(1, rotatePosition, TFT_GOLD);
    break;
  case 6:
    TFTDISPLAY.showBtnPressCircle(2, rotatePosition, TFT_GOLD);
    break;

  default:
    break;
  }

  // water consumption interact
  if (rotatePosition == modeWater && btnReturn == 3) WATERCONS.addConsumed();
  if (rotatePosition == modeWater && btnReturn == 4) WATERCONS.removeConsumed();

  if (rotatePosition == modeWater && btnReturn == 5) LEDS.alarm();
}

// ------------------- SETUP / LOOP -------------------
/**
 * set up device with all classes and start values
 */
void setup()
{
  Serial.begin(115200);
  Serial.println("Starting up...");

  TFTDISPLAY.begin();
  DHTSENSOR.begin();
  GYROSENSOR.begin();
  GASSENSOR.begin();
  BTNS.begin();
  LEDS.begin();

  delay(1000);

  LEDS.showAll(255, 50, 50);
}

/**
 * loops through all checks and manage methods
 */
void loop()
{
  unsigned long currentMillis = millis();

  if (currentMillis - prevMillsGYRO >= intervalGYRO)
  {
    prevMillsGYRO = currentMillis;
    gyroRuntime();
  }

  if (currentMillis - prevMillsMODE >= intervalMODE)
  {
    prevMillsMODE = currentMillis;
    manageModes();
  }

  if (currentMillis - prevMillsBTN >= intervalBTN)
  {
    prevMillsBTN = currentMillis;
    manageBtns();
  }
}

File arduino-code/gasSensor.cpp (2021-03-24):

#include "gasSensor.h"

/**
 * Constructor
 */
GasClass::GasClass()
{
}

/**
 * initialise Gas-sensor
 * @return {bool} success
 */
bool GasClass::begin()
{
  mq135 = new MQUnifiedsensor("ESP-32", 5.0, 12, analogGasPin, "MQ-135");
  mq135->setRegressionMethod(1);
  mq135->init();

  Serial.print("Calibrating please wait.");
  float calcR0 = 0;
  for (int i = 1; i <= 10; i++)
  {
    mq135->update(); // Update data, the arduino will be read the voltage on the analog pin
    calcR0 += mq135->calibrate(3.6);
    Serial.print(".");
  }
  mq135->setR0(calcR0 / 10);
  Serial.println(" done!.");

  if (isinf(calcR0))
  {
    Serial.println("Warning: Conection issue founded, R0 is infite (Open circuit detected) please check your wiring and supply");
    return false;
  }
  if (calcR0 == 0)
  {
    Serial.println("Warning: Conection issue founded, R0 is zero (Analog pin with short circuit to ground) please check your wiring and supply");
    return false;
  }

  return true;
}

/**
 * reads sensor values and save in variables
 * and returns CO2 value
 * @return {float} CO2
 */
float GasClass::read()
{
  mq135->update();

  mq135->setA(605.18);
  mq135->setB(-3.937);      // Configurate the ecuation values to get CO concentration
  CO = mq135->readSensor(); // Sensor will read PPM concentration using the model and a and b values setted before or in the setup

  mq135->setA(77.255);
  mq135->setB(-3.18);            // Configurate the ecuation values to get Alcohol concentration
  Alcohol = mq135->readSensor(); // Sensor will read PPM concentration using the model and a and b values setted before or in the setup

  mq135->setA(110.47);
  mq135->setB(-2.862);       // Configurate the ecuation values to get CO2 concentration
  CO2 = co2Calibrate + mq135->readSensor(); // Sensor will read PPM concentration using the model and a and b values setted before or in the setup

  mq135->setA(44.947);
  mq135->setB(-3.445);           // Configurate the ecuation values to get Tolueno concentration
  Tolueno = mq135->readSensor(); // Sensor will read PPM concentration using the model and a and b values setted before or in the setup

  mq135->setA(102.2);
  mq135->setB(-2.473);       // Configurate the ecuation values to get NH4 concentration
  NH4 = mq135->readSensor(); // Sensor will read PPM concentration using the model and a and b values setted before or in the setup

  mq135->setA(34.668);
  mq135->setB(-3.369);           // Configurate the ecuation values to get Acetona concentration
  Acetona = mq135->readSensor(); // Sensor will read PPM concentration using the model and a and b values setted before or in the setup

  return CO2;
}

/**
 * creates a Serial print with all data
 * @return void
 */
void GasClass::serialPrint()
{
  read();
  Serial.print("|   ");
  Serial.print(CO);
  Serial.print("   |   ");
  Serial.print(Alcohol);
  Serial.print("   |   ");
  Serial.print(CO2); // + 400 cause it's always there ?!
  Serial.print("   |   ");
  Serial.print(Tolueno);
  Serial.print("   |   ");
  Serial.print(NH4);
  Serial.print("   |   ");
  Serial.print(Acetona);
  Serial.println("   |");
}

/**
 * calculates scale position 
 * of gas between 0 and 10
 * @return {int} scalePosition
 */
int GasClass::getGasRelValue()
{
  float relative = 10.0 / float(gasMax - gasMin);
  relative *= read() - gasMin;
  return round(relative);
}

/**
 * color of gas on the scale 
 * @return {int32_t} hexColor (24 Bit rgb)
 */
int32_t GasClass::getGasRelColor()
{
  switch (getGasRelValue())
  {
  case 0:
    return 0x0AFA0A;
  case 1:
  case 2:
    return 0xE2FA0A;
  case 3:
  case 4:
    return 0xFFB30A;
  case 5:
  case 6:
    return 0xFF5F0A;
  case 7:
  case 8:
    return 0xCC0A0A;
  case 9:
  case 10:
    return 0x4D0A0A;
  default:
    return 0xFFFFFF; // white
  }
}

GasClass GASSENSOR = GasClass();

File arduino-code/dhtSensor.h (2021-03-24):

/**
 * Verkabelung:
 *  DHT  -  +   -   out
 *   |      |   |    |
 * ESP32 - 3v3 GND  15
 */

#ifndef _INFOVIS_DHT_H_
#define _INFOVIS_DHT_H_

#include <Arduino.h>
#include <DHT.h>

class DhtClass
{
private:
    const int dhtType = 22;
    const int dhtPin = 15;
    DHT* dht;

    const int tempMin = -20;
    const int tempMax = 45;
    const int tempCalibrate = -9;

    const int humMin = 0;
    const int humMax = 100;

public:
    DhtClass();
    bool begin();
    float getTemperature();
    float getHumidity();

    int getTempRelValue();
    int32_t getTempRelColor();
    
    int getHumRelValue();
    int32_t getHumRelColor();
};

extern DhtClass DHTSENSOR;

#endif
